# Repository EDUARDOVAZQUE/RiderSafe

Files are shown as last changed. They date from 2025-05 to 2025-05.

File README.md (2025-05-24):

# 🏍️ RIDERSAFE 🏍️
### *Sistema Inteligente de Seguridad y Monitoreo para Motocicletas*

RiderSafe es un sistema de geolocalización y monitoreo en tiempo real diseñado para mejorar la seguridad de las motocicletas en Mixquiahuala de Juárez, Hidalgo, México. Este sistema responde al incremento sostenido del robo de motocicletas en la región, utilizando tecnologías como LoRa, GPS y conectividad 4G para rastrear, controlar y actuar ante eventos sospechosos o situaciones de robo.

---

## 📁 Estructura de Carpetas
- /Software → Archivos .ino, scripts, dashboard
- /Hardware → Fichas técnicas, modelos
- /Documentacion → Manuales, reportes técnicos
- /Diagramas → Diagramas de esquemáticos, flujo de datos

---

### 🧠 Tecnologías Utilizadas

- Lenguaje de programación: C++ (Arduino IDE), HTML, CSS, JavaScript  
- Protocolos de comunicación: LoRa, I2C, SPI, MQTT, ESPNOW, AT Commands  
- Sensores y módulos: MPU6050, GPS, SIM7600G-H  
- Servicios en la nube: Mosquitto (servidor MQTT)  
- Interfaces de usuario: Dashboard web con NODE-RED  

---

### ⚙️ Funcionalidades

- Geolocalización precisa vía GPS  
- Comunicación de largo alcance con LoRa  
- Transmisión de datos por 4G a la nube vía MQTT  
- Detección de inclinación y aceleración con MPU6050  
- Activación remota de un cortacorriente  
- Visualización de estado de batería, señal LoRa, estado del relé  
- Modularidad para visualizar datos y controlar el sistema desde una aplicación web o dashboard  

---

## 🖥️ Instrucciones de Instalación

### 🔌 En Heltec LoRa 32 v2 (Llavero Portátil)

1. Cargar código `LlaveroPortatilv3`  
2. Instalar en la PCB impresa 1  

### 🔁 En Heltec LoRa 32 v2 (Nodo Puente)

1. Cargar código `Heltec-gateway`  
2. Instalar en la PCB impresa 2  

### 🌐 En LilyGO (Nodo SIM7600)

1. Cargar código `SendMQTT_data`  
2. Instalar en la PCB impresa 2  

### 🧠 En Raspberry Pi

1. Instalar IoT Stack  
2. Importar JSON con el nombre `RiderSafe.json`  
3. Ejecutar script para Grafana  

---

### ⚙️ Configuración

- Usar el regulador de voltaje a **5V**, establecer ese voltaje antes de la instalación  
- Algunos sensores **MPU6050** no son reconocidos por la biblioteca Adafruit  
  - Cargar código `who_am_i` y reemplazar dirección del dispositivo en la librería  

---

### 📸 Escenarios de Uso

🎥 Mira la demostración en video:  
Ver Video (https://youtu.be/g3GmbGhdLP4)

---

### 📘 Casos de Uso

- **Usuario Final**: consulta ubicación y estado desde app web, puede activar o desactivar relé remotamente.  
- **Administrador**: monitorea estados, accede a estadísticas y análisis.  
- **Proveedor**: configura módulos, actualiza firmware, da mantenimiento.  

---

## 🚧 Limitaciones y Mejoras Futuras

### ⚠️ Limitaciones actuales

- Limitada tolerancia a pérdida de energía prolongada  
- Falta de protecciones de alto o bajo voltaje  
- El dashboard funciona con limitaciones sin internet  
- Inestabilidad e incompatibilidad de datos en Grafana  

### 🌱 Mejoras propuestas

- Añadir almacenamiento local cuando no haya conexión  
- Rediseñar interfaz web  
- Mejorar duración de batería  
- Agregar protecciones contra alto voltaje  
- Encendido y apagado automático de la motocicleta  
- Implementar batería de emergencia  
- Medidor de batería en ambos dispositivos  
- Relevador lógico de 3.3V especializado  
- Agregar más casos para alertas  
- Uso de PCB impresa  

---

## 🤝 Contribuciones

¿Quieres aportar al proyecto?

1. Haz un fork del repositorio  
2. Crea una nueva rama
3. Realiza cambios y commits descriptivos
4. Reporta errores o mejoras en la sección "Issues"

## 📜 Licencia
---

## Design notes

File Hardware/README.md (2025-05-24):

# 🔩 RiderSafe – Componentes de Hardware

Este documento detalla los componentes de hardware utilizados en el desarrollo del sistema RiderSafe, incluyendo placas de desarrollo, sensores, actuadores y módulos de comunicación.

---

## 🧠 Placas de Desarrollo

### 1. Heltec WiFi LoRa 32 (V2) ×2

Microcontrolador ESP32 con pantalla OLED integrada y módulo LoRa SX1276 para comunicación de largo alcance.

- Uso en el proyecto:
  - Nodo cliente portátil
  - Nodo puente intermedio
- Comunicación: SPI (LoRa), I2C (sensores), UART (comunicación entre nodos)
- Voltaje de operación: 3.3V

🔗 [Ficha técnica – Heltec WiFi LoRa 32 V2](https://heltec.org/project/wifi-lora-32v2/)
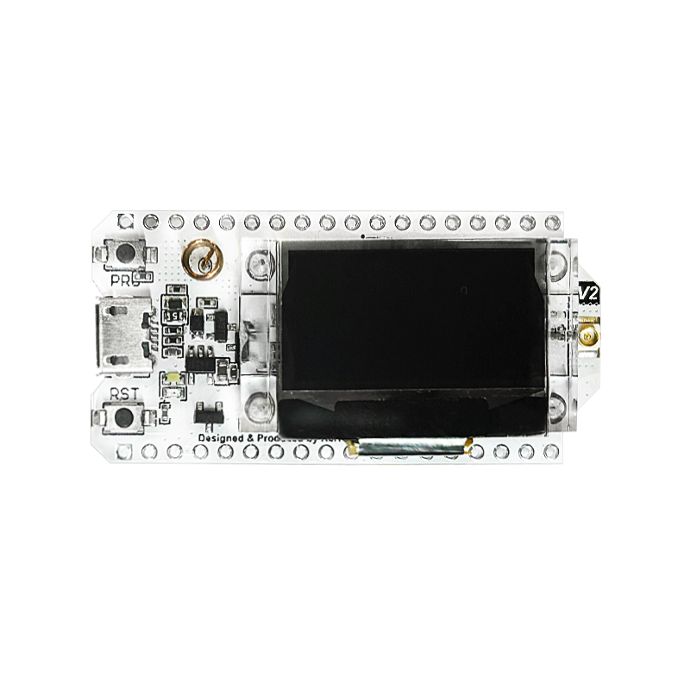
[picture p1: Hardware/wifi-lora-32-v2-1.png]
Logo de Heltec


---

### 2. LilyGO T-SIM7600G-H ×1

Placa basada en ESP32 con módulo SIM7600G-H incorporado para comunicación por red celular 4G, GPS y GNSS.

- Uso en el proyecto:
  - Nodo central de transmisión 4G
- Protocolos: UART (AT Commands), MQTT
- Funciones: Envío de datos por internet, GPS integrado

🔗 [Ficha técnica – LilyGO T-SIM7600G-H](https://lilygo.cc/products/t-sim7600)

---

## 🔧 Sensores y Módulos

### 3. MPU6050 ×1

Sensor de movimiento que combina acelerómetro y giroscopio de 3 ejes.

- Uso en el proyecto:
  - Detección de inclinación, aceleración y posibles caídas
- Comunicación: I2C
- Rango de voltaje: 3.3V a 5V

🔗 [Ficha técnica – MPU6050 (InvenSense)](https://invensense.tdk.com/wp-content/uploads/2015/02/MPU-6000-Datasheet1.pdf)

---

### 4. Módulo Relevador SRD-05VDC-SL-C ×1

Actuador electromecánico que permite abrir o cerrar circuitos eléctricos mediante una señal digital.

- Uso en el proyecto:
  - Activación/corte del sistema eléctrico de la motocicleta
- Voltaje de activación: 5V
- Tipo: Normalmente abierto (NO) / normalmente cerrado (NC)

🔗 [Ficha técnica – Relevador SRD-05VDC-SL-C](https://naylampmechatronics.com/img/cms/000263/SRD-05VDC-SL-C-Datasheet.pdf)

---

### 5. Convertidor Lógico de 4 Canales (Bidireccional) ×1

Permite la comunicación entre dispositivos con diferentes niveles de voltaje (3.3V ↔ 5V).

- Uso en el proyecto:
  - Interfaz segura entre módulos a diferentes voltajes (por ejemplo, ESP32 y relevador)
- Compatible con I2C y señales digitales

🔗 *Enlace genérico según el módulo utilizado. (Puedes incluir tu proveedor específico si lo tienes)*

---
---

### 6. Regulador de Voltaje Buck LM2596 ×1

Módulo convertidor **step-down** (reductor de voltaje) basado en el chip LM2596 de Texas Instruments, utilizado para alimentar los módulos electrónicos desde fuentes como la batería de una motocicleta.

- **Uso en el proyecto:**
  - Reduce los 12–14V del sistema eléctrico de la moto a 5V estables
  - Alimenta de forma segura la LilyGO SIM7600G-H y otros componentes sensibles
- **Voltaje de entrada recomendado:** 7V a 24V DC
- **Voltaje de salida típico:** Ajustable, comúnmente calibrado a 5V
- **Corriente de salida:** Hasta 2A
- **Frecuencia de conmutación:** 150 kHz

🔗 [Ficha técnica oficial – LM2596 (Texas Instruments)](https://www.ti.com/lit/ds/symlink/lm2596.pdf)

> ⚠️ **Precaución**: Algunos módulos LM2596 económicos requieren calibración manual. Gira el potenciómetro con cuidado y confirma la salida de 5.00V exactos antes de conectar tu placa.

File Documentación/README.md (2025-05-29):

## 📁 documentacion

### Descripción

Esta carpeta incluye detalles sobre los archivos stl.

### Contenido

* **Carcasa prototipo**
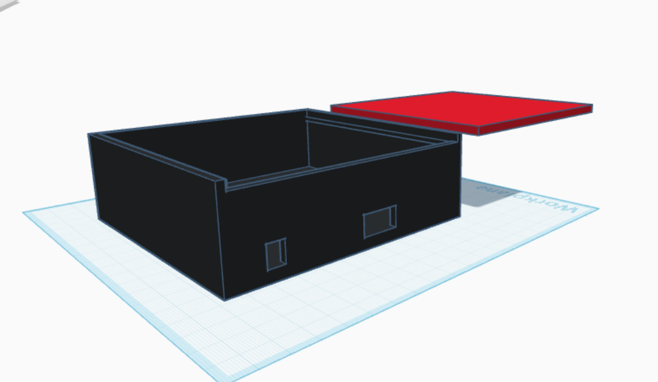
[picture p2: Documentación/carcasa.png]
Carcasa prototipo

* **Carcasa portatil**
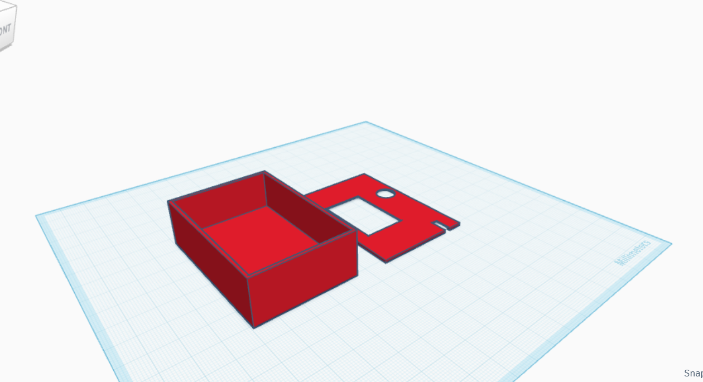
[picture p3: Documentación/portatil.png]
Carcasa portatil


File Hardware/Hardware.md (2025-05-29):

# 🔩 RiderSafe – Componentes de Hardware

Este documento detalla los componentes de hardware utilizados en el desarrollo del sistema RiderSafe, incluyendo placas de desarrollo, sensores, actuadores y módulos de comunicación.

---

## 🧠 Placas de Desarrollo

### 1. Heltec WiFi LoRa 32 (V2) ×2

Microcontrolador ESP32 con pantalla OLED integrada y módulo LoRa SX1276 para comunicación de largo alcance.

- Uso en el proyecto:
  - Nodo cliente portátil
  - Nodo puente intermedio
- Comunicación: SPI (LoRa), I2C (sensores), UART (comunicación entre nodos)
- Voltaje de operación: 3.3V

Placa heltec
🔗 [Ficha técnica – Heltec WiFi LoRa 32 V2](https://heltec.org/project/wifi-lora-32v2/)

---

### 2. LilyGO T-SIM7600G-H ×1

Placa basada en ESP32 con módulo SIM7600G-H incorporado para comunicación por red celular 4G, GPS y GNSS.

- Uso en el proyecto:
  - Nodo central de transmisión 4G
- Protocolos: UART (AT Commands), MQTT
- Funciones: Envío de datos por internet, GPS integrado

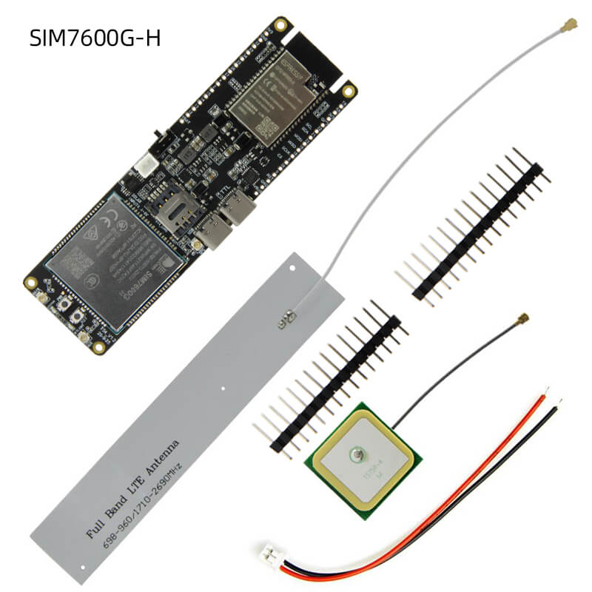
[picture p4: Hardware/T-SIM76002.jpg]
Placa LilyGO

🔗 [Ficha técnica – LilyGO T-SIM7600G-H](https://lilygo.cc/products/t-sim7600)

---

## 🔧 Sensores y Módulos

### 3. MPU6050 ×1

Sensor de movimiento que combina acelerómetro y giroscopio de 3 ejes.

- Uso en el proyecto:
  - Detección de inclinación, aceleración y posibles caídas
- Comunicación: I2C
- Rango de voltaje: 3.3V a 5V

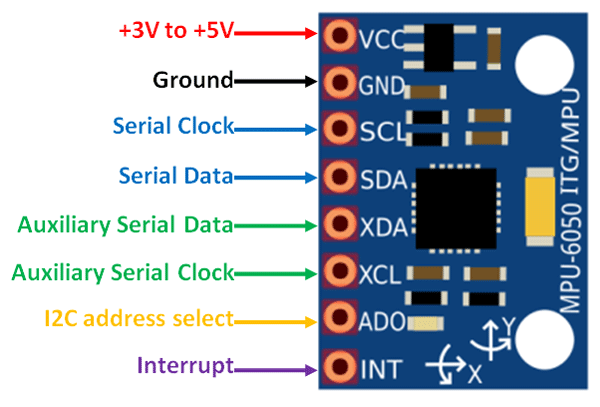
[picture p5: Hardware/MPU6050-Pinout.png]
Sensor MPU6050

🔗 [Ficha técnica – MPU6050 (InvenSense)](https://invensense.tdk.com/wp-content/uploads/2015/02/MPU-6000-Datasheet1.pdf)

---

### 4. Módulo Relevador SRD-05VDC-SL-C ×1

Actuador electromecánico que permite abrir o cerrar circuitos eléctricos mediante una señal digital.

- Uso en el proyecto:
  - Activación/corte del sistema eléctrico de la motocicleta
- Voltaje de activación: 5V
- Tipo: Normalmente abierto (NO) / normalmente cerrado (NC)

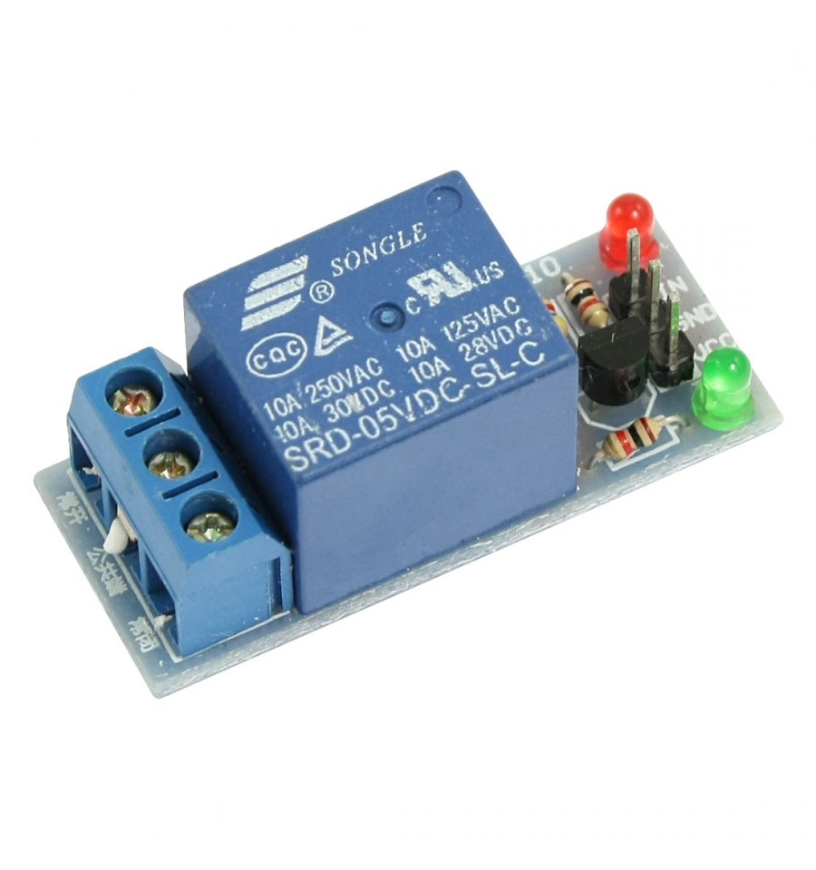
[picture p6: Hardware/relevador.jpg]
Relevador

🔗 [Ficha técnica – Relevador SRD-05VDC-SL-C](https://naylampmechatronics.com/img/cms/000263/SRD-05VDC-SL-C-Datasheet.pdf)

---

### 5. Convertidor Lógico de 4 Canales (Bidireccional) ×1

Permite la comunicación entre dispositivos con diferentes niveles de voltaje (3.3V ↔ 5V).

- Uso en el proyecto:
  - Interfaz segura entre módulos a diferentes voltajes (por ejemplo, ESP32 y relevador)
- Compatible con I2C y señales digitales

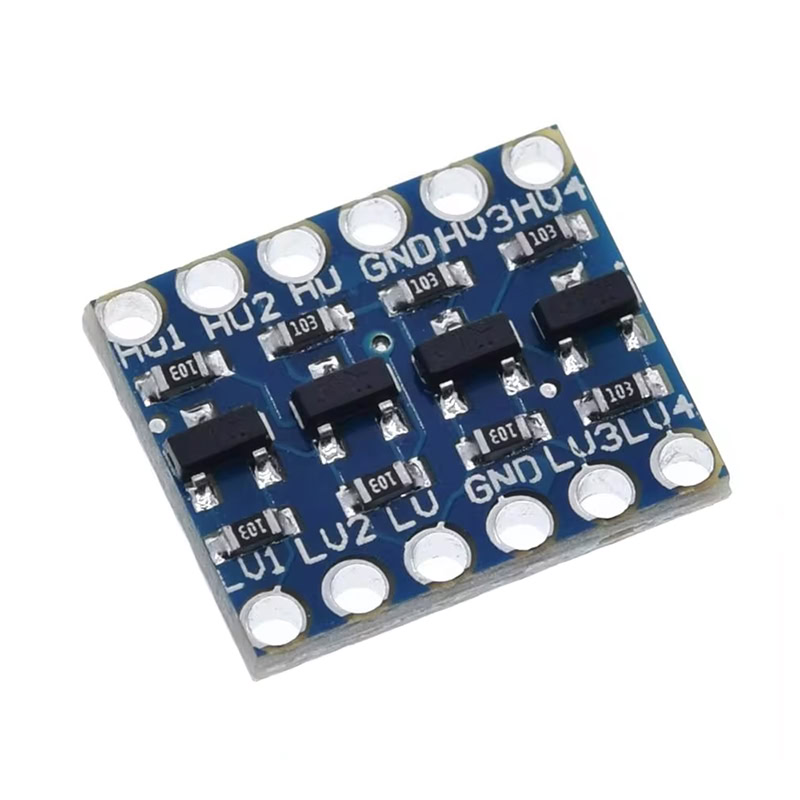
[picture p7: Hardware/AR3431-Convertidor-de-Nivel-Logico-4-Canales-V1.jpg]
Convertidor lógico


🔗 *Enlace genérico según el módulo utilizado. (Puedes incluir tu proveedor específico si lo tienes)*

---
---

### 6. Regulador de Voltaje Buck LM2596 ×1

Módulo convertidor **step-down** (reductor de voltaje) basado en el chip LM2596 de Texas Instruments, utilizado para alimentar los módulos electrónicos desde fuentes como la batería de una motocicleta.

- **Uso en el proyecto:**
  - Reduce los 12–14V del sistema eléctrico de la moto a 5V estables
  - Alimenta de forma segura la LilyGO SIM7600G-H y otros componentes sensibles
- **Voltaje de entrada recomendado:** 7V a 24V DC
- **Voltaje de salida típico:** Ajustable, comúnmente calibrado a 5V
- **Corriente de salida:** Hasta 2A
- **Frecuencia de conmutación:** 150 kHz

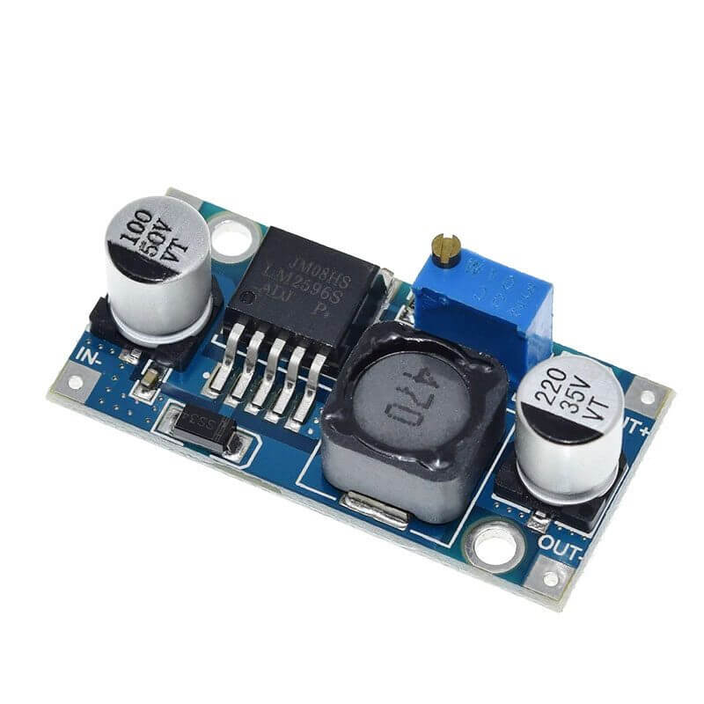
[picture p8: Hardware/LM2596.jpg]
Regulador de voltaje

🔗 [Ficha técnica oficial – LM2596 (Texas Instruments)](https://www.ti.com/lit/ds/symlink/lm2596.pdf)

> ⚠️ **Precaución**: Algunos módulos LM2596 económicos requieren calibración manual. Gira el potenciómetro con cuidado y confirma la salida de 5.V exactos antes de conectar tu placa.

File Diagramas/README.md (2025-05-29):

## 📁 diagramas

### Descripción

Esta carpeta contiene los diagramas que representan la arquitectura y el flujo de funcionamiento del sistema RiderSafe. Estos diagramas son esenciales para comprender la interacción entre los diferentes componentes del sistema.

### Contenido

* **Diagrama de flujo de datos**: Ilustra cómo se procesan y transmiten los datos dentro del sistema.
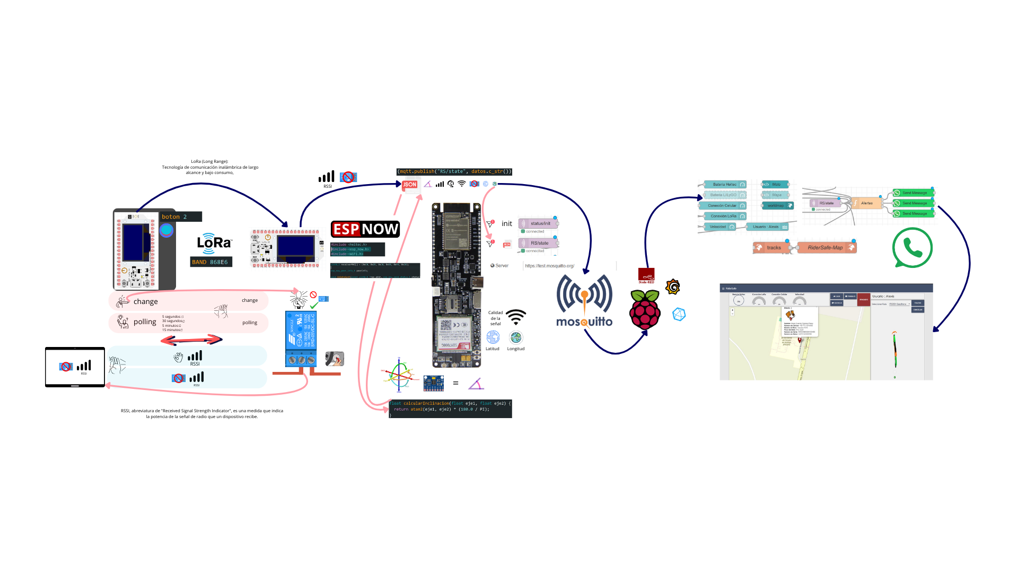
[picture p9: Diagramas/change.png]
flujo de datos


* **Diagrama de arquitectura del sistema**: Muestra cómo se interconectan los módulos de hardware y software.

*Diagrama de arquitectura prototipo*
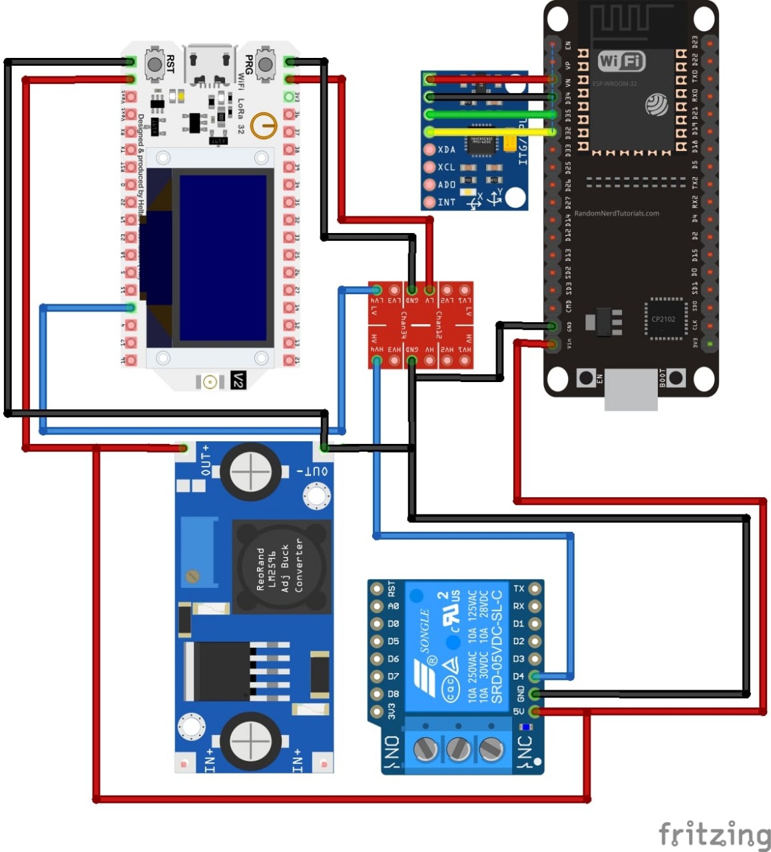
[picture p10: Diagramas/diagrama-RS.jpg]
Diagrama prototipo


*Diagrama de arquitectura del sistema portatil*
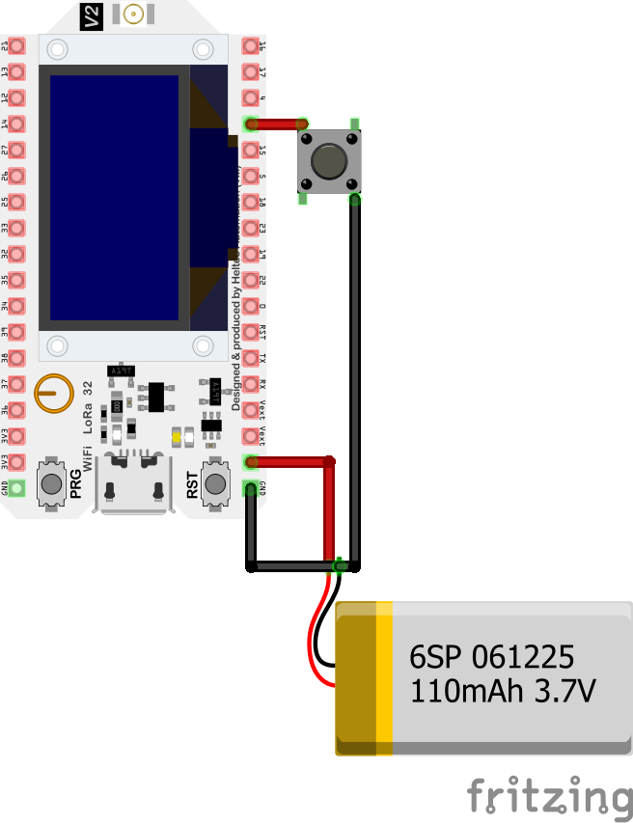
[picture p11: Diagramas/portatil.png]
Diagrama dispositivo portatil


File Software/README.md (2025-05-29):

## 📁 software

### Descripción

Esta carpeta contiene el código fuente del software que controla el sistema RiderSafe. Incluye scripts para la recopilación de datos, comunicación entre módulos y envío de información a servidores remotos.

### Contenido

* **Código fuente**: Archivos `.ino` y `.cpp` con la lógica del sistema.

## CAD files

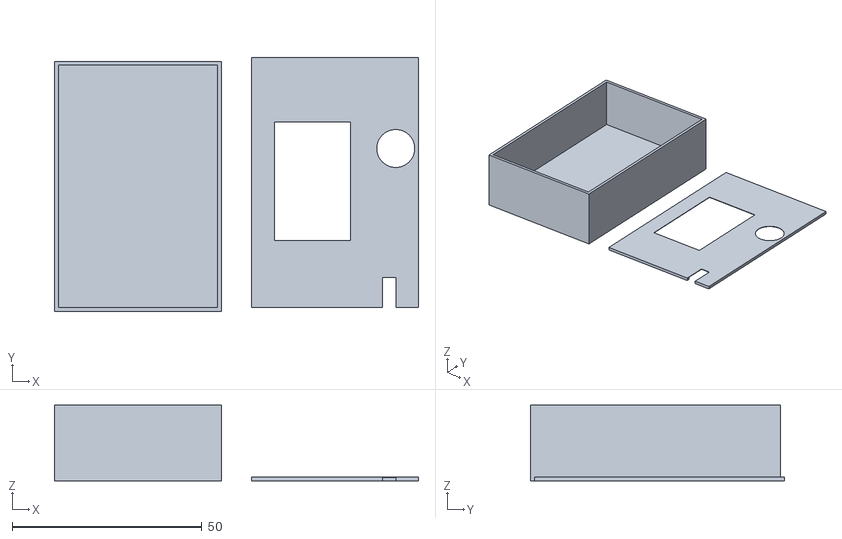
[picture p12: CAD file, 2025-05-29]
Documentación/Heltec-portatil.stl
96.0 x 67.0 x 20.0

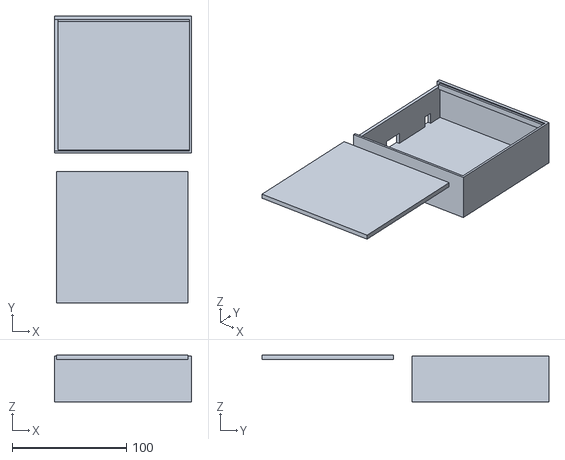
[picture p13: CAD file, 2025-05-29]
Documentación/carcasa.stl
120.0 x 251.0 x 41.0

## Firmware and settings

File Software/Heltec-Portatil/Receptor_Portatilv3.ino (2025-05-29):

//llavero
//librerias
#include <heltec.h>
#include <WiFi.h>
#include <PubSubClient.h>
#include <ArduinoJson.h>
#include <Arduino.h>

#define BAND 868E6 //banda de transmicion en Mhz
#define boton 2

bool pantallaEncendida = true;
unsigned long tiempoEncendidoPantalla = 0;
const unsigned long tiempoPantallaActiva = 30000; //30s

float pitch = 120; //pitch de inicio

bool releState = HIGH;
bool btnState = HIGH;

//antirrebote del boton
bool lastBtnState = HIGH;
unsigned long lastDebounceTime = 0;
const int debounceDelay = 50;

//mensaje
String mensajeRecibido = "";
int rssi = 0; //intensidad de la señal LoRa

//variables tiempo
unsigned long previousHello = 0; //polling o envio enfrecuente para saber si aun hay conexion y la intensidad de esta.
const unsigned long helloInterval = 10000;

// Configuración WiFi y MQTT para obtener el pitch
const char* ssid = "LobosIT";
const char* password = "V4M4LVU5H11113k";
const char* mqtt_server = "192.168.137.60"; //raspberry pi

bool dataReceived = false; 

WiFiClient espClient;
PubSubClient client(espClient);

void setup() {
  Serial.begin(115200);
  pinMode(boton, INPUT_PULLUP);
  Heltec.begin(true, true, true);
  LoRa.begin(BAND, true);
  LoRa.receive();

  Heltec.display->setTextAlignment(TEXT_ALIGN_LEFT);
  Heltec.display->setFont(ArialMT_Plain_10);
  delay(500);
  actualizarDisplay();

  setup_wifi();
  client.setServer(mqtt_server, 1883); //Algunas maquinas windows ya tienen ocupado el puerto 1883, asi que puede cambiar a 1884 o superior
  client.setCallback(callback);
}

void actualizarDisplay() {
  if (!pantallaEncendida) return;

  Heltec.display->clear();
  Heltec.display->setTextAlignment(TEXT_ALIGN_CENTER);
  Heltec.display->drawString(50, 0, "HOLA SOY");
  Heltec.display->drawString(50, 12, "La Locura :)");

 int centerX = 32, centerY = 60, radius = 18;
float angleRad = radians(pitch);

// Dibujar medio círculo (ejemplo: de 0° a 180°)
for (int angle = 0; angle <= 180; angle += 5) {
  float a = radians(angle);
  int x = centerX + radius * cos(a - PI);  // Corrige orientación
  int y = centerY + radius * sin(a - PI);
  Heltec.display->setPixel(x, y);  // Dibuja punto del semicírculo
}

// Calcular coordenadas del extremo de la aguja
int xEnd = centerX + radius * cos(angleRad - PI);
int yEnd = centerY + radius * sin(angleRad - PI);

// Dibuja línea del ángulo (más gruesa: 3 líneas paralelas)
for (int offset = -1; offset <= 1; offset++) {
  Heltec.display->drawLine(centerX + offset, centerY, xEnd + offset, yEnd);
}


  Heltec.display->setTextAlignment(TEXT_ALIGN_LEFT);
  Heltec.display->drawString(87, 10, "LoRa");
  //crea las barras para mostrar la intensidad del RSSI
  int bars = map(rssi, -120, -40, 0, 4);
  for (int i = 0; i < 4; i++) {
    int barHeight = (i + 1) * 3;
    int x = 114 + i * 4;
    int y = 35 - barHeight;
    if (i < bars) Heltec.display->fillRect(x, y, 3, barHeight);
    else Heltec.display->drawRect(x, y, 3, barHeight);
  }

  Heltec.display->drawString(84, 20, String(rssi) + " dBm");

//candado
  int cx = 100, cy = 50;
  Heltec.display->drawRect(cx, cy, 12, 10);

  if (releState == LOW) {
    Heltec.display->drawLine(cx + 3, cy, cx + 3, cy - 6);
    Heltec.display->drawLine(cx + 9, cy, cx + 9, cy - 6);
    Heltec.display->drawLine(cx + 3, cy - 6, cx + 9, cy - 6);
  } else {
    Heltec.display->drawLine(cx + 9, cy, cx + 9, cy - 6);
    Heltec.display->drawLine(cx + 3, cy - 6, cx + 9, cy - 6);
  }

  for (int i = 3; i <= 7; i++)
    Heltec.display->setPixel(cx + 6, cy + i);

  Heltec.display->display();
}

void enviarHello() {
 // Serial.println("Enviando: hola"); //emvia lora
  LoRa.beginPacket();
  LoRa.print("hola");
  LoRa.endPacket();
  LoRa.receive();

  unsigned long timeout = millis() + 3000;
  mensajeRecibido = "";
  while (millis() < timeout && mensajeRecibido == "") {
    recibirMensaje();
  }

  if (mensajeRecibido != "") {
    if (mensajeRecibido == "ok") {
      rssi = LoRa.packetRssi();
      //Serial.println("Respuesta 'ok' recibida. RSSI: " + String(rssi) + " dBm");
    } else {
      //Serial.println("Respuesta diferente a 'ok': " + mensajeRecibido);
    }
  } else {
    //Serial.println("Sin respuesta a 'hola'");
  }
  actualizarDisplay();
}

void enviarChange() { //para cambio del relevador
  String mensaje = "change"; //mensaje que se envia a la lora moto
  Serial.println("Enviando: " + mensaje);
  LoRa.beginPacket();
  LoRa.print("mensaje");
  LoRa.endPacket();
  LoRa.receive();

  unsigned long timeout = millis() + 3000;
  mensajeRecibido = "";
  while (millis() < timeout && mensajeRecibido == "") {
    recibirMensaje();
  }

  if (mensajeRecibido != "") {
    if (mensajeRecibido == "1" || mensajeRecibido == "0") {
      releState = (mensajeRecibido == "1");
      Serial.println("Estado actualizado a: " + mensajeRecibido);
    } else {
      Serial.println("Respuesta inesperada: " + mensajeRecibido);
    }
  } else {
    Serial.println("Sin respuesta a 'change'");
  }
  actualizarDisplay();
}

void recibirMensaje() {
  int packetSize = LoRa.parsePacket();
  if (packetSize) {
    mensajeRecibido = "";
    while (LoRa.available()) {
      mensajeRecibido += (char)LoRa.read();
    }
    rssi = LoRa.packetRssi();
    Serial.println("Recibido: " + mensajeRecibido + ", RSSI: " + String(rssi) + " dBm");

    // Nuevo: analizar pitch recibido
    if (mensajeRecibido.indexOf("\"pitch\"") != -1) {
  int start = mensajeRecibido.indexOf(":") + 1;
  int end = mensajeRecibido.indexOf("}");
  if (start > 0 && end > start) {
    String pitchStr = mensajeRecibido.substring(start, end);
    pitch = pitchStr.toFloat();
    Serial.println("Pitch actualizado (JSON): " + String(pitch));
    actualizarDisplay();

  String json = "\"pitch\""
  }
}

  }
}

void loop() {
  if (!client.connected()) {
    reconnect();
  }
  client.loop();
  bool reading = digitalRead(boton);
  if (reading != lastBtnState) {
    lastDebounceTime = millis();
  }

  if ((millis() - lastDebounceTime) > debounceDelay) {
    if (reading != btnState) {
      btnState = reading;
      if (btnState == LOW) {
        enviarChange();
        encenderPantalla();
      }
    }
  }
  lastBtnState = reading;

  unsigned long currentMillis = millis();
  if (currentMillis - previousHello >= helloInterval) {
    previousHello = currentMillis;
    enviarHello();
  }

  if (pantallaEncendida && millis() - tiempoEncendidoPantalla > tiempoPantallaActiva) {
    pantallaEncendida = false;
    Heltec.display->displayOff();
  }

  delay(10);
}

void encenderPantalla() {
  if (!pantallaEncendida) {
    pantallaEncendida = true;
    Heltec.display->displayOn();
  }
  tiempoEncendidoPantalla = millis();
  actualizarDisplay();
}

void setup_wifi() {
  delay(10);
  // We start by connecting to a WiFi network
  Serial.println();
  Serial.print("Connecting to ");
  Serial.println(ssid);

  WiFi.begin(ssid, password);

  while (WiFi.status() != WL_CONNECTED) {
    delay(500);
    Serial.print(".");
  }

  Serial.println("");
  Serial.println("WiFi connected");
  Serial.println("IP address: ");
  Serial.println(WiFi.localIP());
}

void callback(char* topic, byte* message, unsigned int length) { //funcion para leer topico RS-pitch
  Serial.print("Mensaje MQTT en topic: ");
  Serial.println(topic);

  String messageTemp;
  for (int i = 0; i < length; i++) {
    messageTemp += (char)message[i];
  }

  Serial.print("Contenido del mensaje: ");
  Serial.println(messageTemp);

  if (String(topic) == "RS-pitch") {
    // Parsear JSON del mensaje MQTT
    StaticJsonDocument<128> doc;
    DeserializationError error = deserializeJson(doc, messageTemp);

    if (!error && doc.containsKey("pitch")) {
      pitch = doc["pitch"];
      Serial.print("Pitch MQTT actualizado a: ");
      Serial.println(pitch);
      encenderPantalla(); // para asegurar que se ve lapantalla
      actualizarDisplay();
    } else {
      Serial.println("Error al parsear JSON o 'pitch' no encontrado.");
    }
  }
}

void reconnect() {
  // Loop until we're reconnected
  while (!client.connected()) {
    Serial.print("Attempting MQTT connection...");
    // Attempt to connect
    if (client.connect("Llavero")) {
      Serial.println("connected");
      // Subscribe
      client.subscribe("RS-pitch");
    } else {
      Serial.print("failed, rc=");
      Serial.print(client.state());
      Serial.println(" try again in 5 seconds");
      // Wait 5 seconds before retrying
      delay(5000);
    }
  }

}

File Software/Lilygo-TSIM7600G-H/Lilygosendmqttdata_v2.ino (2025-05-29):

//lilygo
#define TINY_GSM_MODEM_SIM7600
#define SerialMon Serial
#define SerialAT Serial1
#define TINY_GSM_DEBUG SerialMon
#define TINY_GSM_USE_GPRS true
#define TINY_GSM_USE_WIFI false
#define GSM_PIN ""
#define uS_TO_S_FACTOR 1000000ULL
#define TIME_TO_SLEEP 60
#define UART_BAUD 115200
#define MODEM_DTR 25
#define MODEM_TX 27
#define MODEM_RX 26
#define MODEM_PWRKEY 4
#define MODEM_RI 33
#define MODEM_FLIGHT 25
#define MODEM_STATUS 34
#define SD_MISO 2
#define SD_MOSI 15
#define SD_SCLK 14
#define SD_CS 13
#define LED_PIN 12



#include <esp_now.h>
#include <WiFi.h>
#include <TinyGsmClient.h>
#include <PubSubClient.h>
#include <Ticker.h>
#include <SPI.h>
#include <SD.h>
#include <Arduino.h>
#include <ArduinoJson.h>  // Incluye esta librería si puedes usarla
#include <Adafruit_MPU6050.h>
#include <Adafruit_Sensor.h>
//Sensor MPU6050
Adafruit_MPU6050 mpu;
sensors_event_t a, g, temp;
float accX, accY, accZ;
float gyroX, gyroY, gyroZ;
float temperature;
float alpha = 0.5;  // Factor de suavizado
float filteredAccX, filteredAccY, filteredAccZ;

String releState = "false";
String intL = "0";

bool mqttWasConnected = true;  // Asume que inicialmente estaba conectado

unsigned long lastMsg = 0;
const long interval = 500;  // Intervalo de publicación en ms

// Your GPRS credentials, if any
const char apn[] = "web.usacellgsm.mx";
const char gprsUser[] = "";
const char gprsPass[] = "";

uint32_t lastReconnectAttempt = 0;
int inicializador = 0;
// MQTT details
const char *broker = "test.mosquitto.org";
const char *topicSensor = "RS/state";
const char *topicInit = "status/init";

//gps variables
float gpsLat = 0.0;
float gpsLon = 0.0;


#ifdef DUMP_AT_COMMANDS
#include <StreamDebugger.h>
StreamDebugger debugger(SerialAT, SerialMon);
TinyGsm modem(debugger);
#else
TinyGsm modem(SerialAT);
#endif
TinyGsmClient client(modem);
PubSubClient mqtt(client);

Ticker tick;

// Structure example to receive data
typedef struct struct_message {
  int releState;
  int intL;
} struct_message;

struct_message myData;
bool dataReceived = false;  // Flag para indicar que se ha recibido data

void OnDataRecv(const esp_now_recv_info *recv_info, const uint8_t *incomingData, int len) {
  // Convertir a String
  String jsonStr = "";
  for (int i = 0; i < len; i++) {
    jsonStr += (char)incomingData[i];
  }

  Serial.print("Mensaje recibido: ");
  Serial.println(jsonStr);

  // Parsear el JSON recibido
  StaticJsonDocument<200> doc;
  DeserializationError error = deserializeJson(doc, jsonStr);

  if (error) {
    Serial.print("Error al parsear JSON: ");
    Serial.println(error.c_str());
    return;
  }

  // Extraer los valores
  myData.releState = doc["releState"];
  myData.intL = doc["intL"];
  dataReceived = true;

  Serial.print("releState: ");
  Serial.println(myData.releState);
  Serial.print("intL: ");
  Serial.println(myData.intL);
}



boolean mqttConnect() {
  SerialMon.print("Connecting to ");
  SerialMon.print(broker);

  boolean status = mqtt.connect("RiderSafe");

  if (status == false) {
    SerialMon.println(" fail");
    return false;
  }
  SerialMon.println(" success");
  return mqtt.connected();
}

void setup() {
  // Initialize Serial Monitor
  Serial.begin(115200);
  delay(10);

  // Set device as a Wi-Fi Station
  WiFi.mode(WIFI_STA);
  initMPU();
  // Init ESP-NOW
  if (esp_now_init() != ESP_OK) {
    Serial.println("Error initializing ESP-NOW");
    return;
  }

  // Register callback for receiving data
  esp_now_register_recv_cb(OnDataRecv);

  // Initialize modem
  SerialAT.begin(UART_BAUD, SERIAL_8N1, MODEM_RX, MODEM_TX);
  pinMode(MODEM_PWRKEY, OUTPUT);
  digitalWrite(MODEM_PWRKEY, HIGH);
  delay(300);
  digitalWrite(MODEM_PWRKEY, LOW);
  pinMode(MODEM_FLIGHT, OUTPUT);
  digitalWrite(MODEM_FLIGHT, HIGH);

  SPI.begin(SD_SCLK, SD_MISO, SD_MOSI, SD_CS);
  if (!SD.begin(SD_CS)) {
    Serial.println("SDCard MOUNT FAIL");
  } else {
    uint32_t cardSize = SD.cardSize() / (1024 * 1024);
    String str = "SDCard Size: " + String(cardSize) + "MB";
    Serial.println(str);
  }

  Serial.println("\nWait...");
  delay(1000);

  DBG("Initializing modem...");
  if (!modem.init()) {
    DBG("Failed to restart modem, delaying 10s and retrying");
  }

  String ret = String(modem.setNetworkMode(2));
  DBG("setNetworkMode:", ret);

  String name = modem.getModemName();
  DBG("Modem Name:", name);

  String modemInfo = modem.getModemInfo();
  DBG("Modem Info:", modemInfo);

#if TINY_GSM_USE_GPRS
  if (GSM_PIN && modem.getSimStatus() != 3) {
    modem.simUnlock(GSM_PIN);
  }
#endif

  SerialMon.print("Waiting for network...");
  if (!modem.waitForNetwork()) {
    SerialMon.println(" fail");
    delay(10000);
    return;
  }
  SerialMon.println(" success");

  if (modem.isNetworkConnected()) {
    SerialMon.println("Network connected");
  }

#if TINY_GSM_USE_GPRS
  SerialMon.print(F("Connecting to "));
  SerialMon.print(apn);
  if (!modem.gprsConnect(apn, gprsUser, gprsPass)) {
    SerialMon.println(" fail");
    delay(10000);
    return;
  }
  SerialMon.println(" success");

  if (modem.isGprsConnected()) {
    SerialMon.println("GPRS connected");
  }
#endif

  // MQTT Broker setup
  mqtt.setServer(broker, 1883);
  mqttConnect();  // Connect to MQTT and publish "Iniciado"
}

void loop() {
  // Make sure we're still registered on the network
  if (!modem.isNetworkConnected()) {
    SerialMon.println("Network disconnected");
    if (!modem.waitForNetwork(180000L, true)) {
      SerialMon.println(" fail");
      delay(10000);
      return;
    }
    if (modem.isNetworkConnected()) {
      SerialMon.println("Network re-connected");
    }

#if TINY_GSM_USE_GPRS
    if (!modem.isGprsConnected()) {
      SerialMon.println("GPRS disconnected!");
      SerialMon.print(F("Connecting to "));
      SerialMon.print(apn);
      if (!modem.gprsConnect(apn, gprsUser, gprsPass)) {
        SerialMon.println(" fail");
        delay(10000);
        return;
      }
      if (modem.isGprsConnected()) {
        SerialMon.println("GPRS reconnected");
      }
    }
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

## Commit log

2025-04-08 Se agrego primeras versiones de las placas heltec
    Versiones funcionales de Comunicacion LoRa-LoRa-Espnow
2025-04-08 Modelo 3D
    Modelo 3D de motocicleta en formato .fbx
2025-05-23 Estructura de las carpetas
2025-05-29 agrergar archivos stl e imagenes
    [Heltec-portatil.stl, carcasa.stl]
